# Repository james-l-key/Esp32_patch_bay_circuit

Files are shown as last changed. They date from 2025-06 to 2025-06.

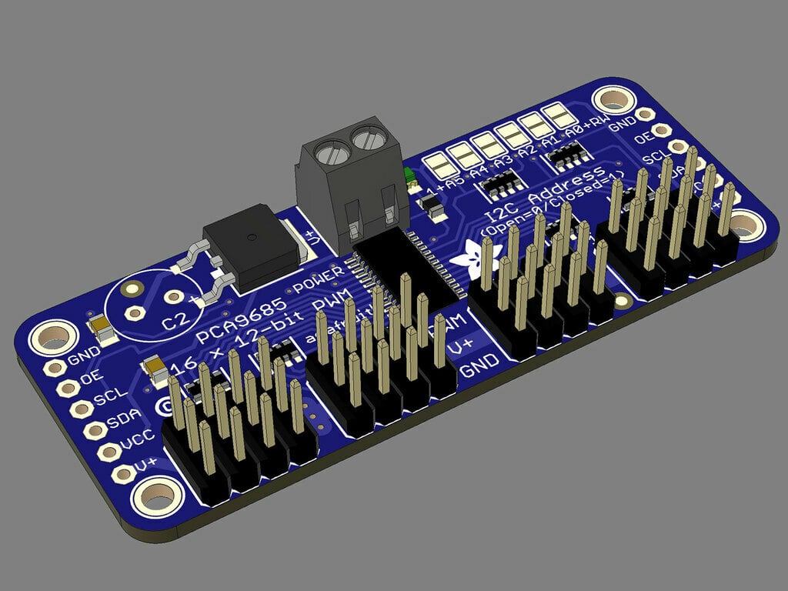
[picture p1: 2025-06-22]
DataSheets/adafruit_products_815_Servo_Driver_16_Channel.jpg

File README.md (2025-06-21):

# ESP32 Patch Bay - Hardware

This repository contains the hardware design files for the **ESP32 Patch Bay**, a project for dynamically reconfiguring guitar pedal signal chains. The main firmware repository can be found [here](https://github.com/phi/Esp32_patch_bay).

## Features
- **Schematic**: Designed in KiCad 9.0 (`circuit.kicad_sch`).
- **8-Pedal Support**: The design supports routing for up to 8 mono guitar pedals.
- **Audio Buffering**: Utilizes TL072 op-amps for input and output buffering to maintain signal integrity.
- **Power Isolation**: A TMA-1215D DC/DC converter generates isolated ±15V rails for the analog audio circuitry, ensuring low-noise operation.

## Hardware
The patch bay is built around the following key components:

- **Microcontroller**: ESP32-S3 (e.g., ESP32-S3-WROOM-1 module).
- **Audio Routing**:
  - CD4051B 8-channel analog multiplexers.
  - 3x TL072 dual op-amps for buffering.
- **Control**:
  - 74HC595 8-bit shift registers to control the multiplexers.
- **Power**:
  - The system is powered by a **12V DC** input.
  - Onboard regulators provide **±15V**, **+5V**, **-5V**, and **+3.3V** for all components.

For a complete list of components, please see the **Bill of Materials (BOM)** in the `docs` folder or the `HARDWARE.md` file.

## Power Requirements
- **Input Power**: The system uses an external **24V DC power supply**.
- **Isolated Dual Rails (±15V)**: Supplied by an LM7815 (+15V) and an inverting MC34063AP (-15V)
- **Regulated Rails**: Onboard linear regulators provide stable **+5V**, **-5V**, and **+3.3V** is supplied by the ESP32-s3-Devkit-C for the digital components and ESP32-S3.

## License
This project is licensed under the MIT License. See the [LICENSE](LICENSE) file for details.

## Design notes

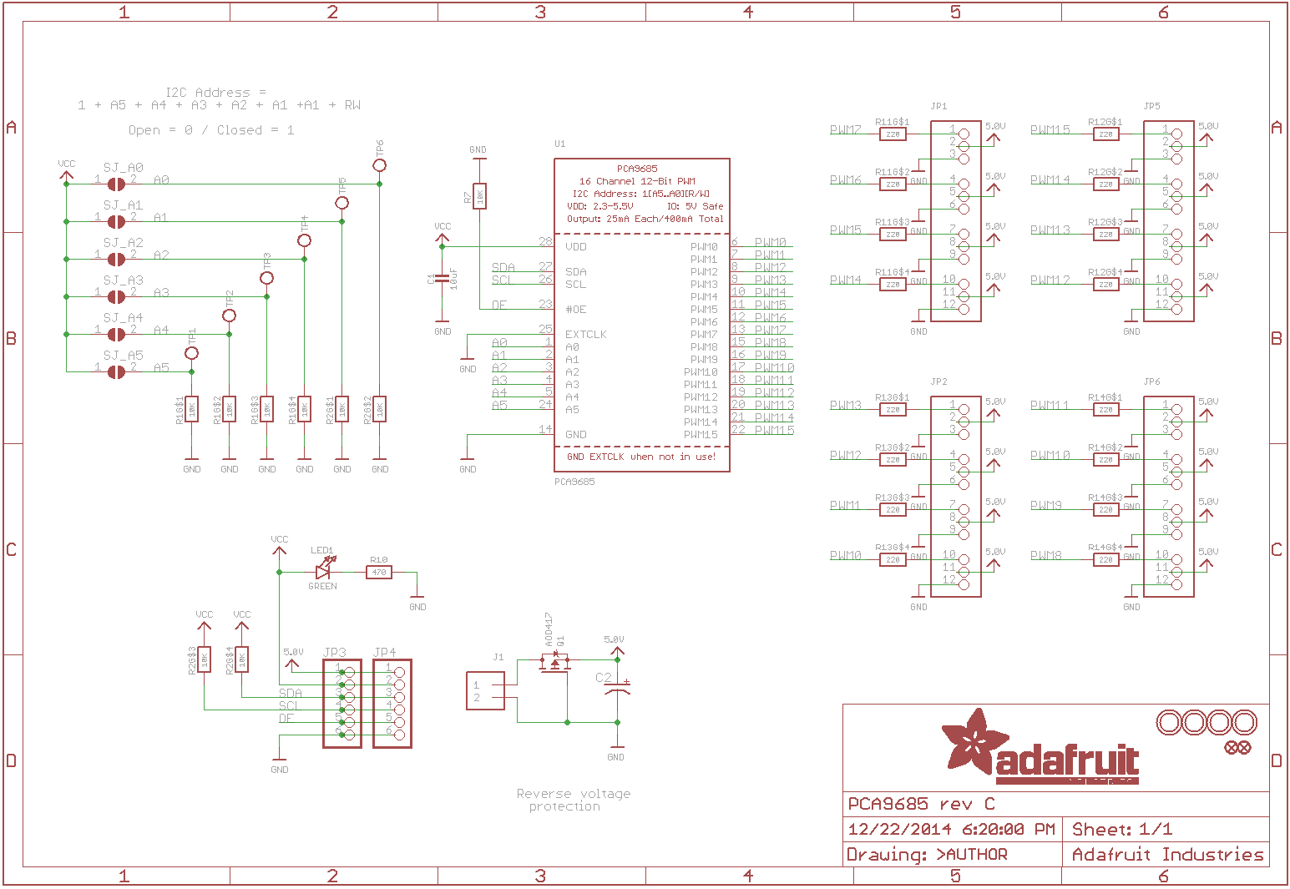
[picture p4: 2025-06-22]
DataSheets/adafruit_products_schem_PCA9685.png

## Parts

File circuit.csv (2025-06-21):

Id | Designator | Footprint | Quantity | Designation | Supplier and ref
1 | C703,C322,C601,C504,C108,C901,C325,C206,C502,C604,C507,C405,C319,C110,C335,C508,C404,C605,C323,C334,C333,C105,C606,C324,C336,C402,C201,C104,C331,C607,C103,C321,C106,C332,C329,C501,C505,C503,C326,C704,C701,C101,C602,C401,C702,C608,C107,C603,C327,C330,C506,C102,C403,C109,C320,C328 | C_Disc_D5.0mm_W2.5mm_P2.50mm | 56 | 0.1uF
2 | R315,R310,R905,R902,R301,R311,R316,R303,R307,R305,R903,R313,R908,R314,R901,R306,R317,R312,R308,R304,R309,R904,R302,R906,R907 | R_Axial_DIN0207_L6.3mm_D2.5mm_P7.62mm_Horizontal | 25 | 10k
3 | U503,U603,U402,U602,U504,U601,U604,U501,U502 | DIP-16_W7.62mm | 9 | CD4051B
4 | U401 | DIP-8_W7.62mm | 1 | ADG419BN
5 | C304,C316,C301,C305,C307,C205,C312,C318,C202,C308,C309,C313,C310,C302,C306,C315,C303,C311,C337,C317,C314 | C_Disc_D5.0mm_W2.5mm_P2.50mm | 21 | 1uF
6 | L302,L303,L304,L501,L602,L601,L502,L301 | WE-UKW_74275010 | 8 | 600R@100Mhz
7 | U704,U901,U701,U702,U703 | DIP-16_W7.62mm | 5 | 74HC595
8 | SW110 | PinHeader_1x02_P2.54mm_Vertical | 1 | Preset
9 | L201 | L_Radial_D10.0mm_P5.00mm_Fastron_07M | 1 | 150uH
10 | C208 | CP_Radial_D5.0mm_P2.50mm | 1 | 220uF 16v
11 | SW109 | PinHeader_1x02_P2.54mm_Vertical | 1 | Pedal_5
12 | J316 | Jack | 1 | FX_S_8
13 | Disp101 | PinHeader_1x04_P2.54mm_Vertical | 1 | ~
14 | J305 | Jack | 1 | FX_R_5
15 | U303,U305,U304,U307,U301,U308,U309,U302,U306 | DIP-8_W7.62mm | 9 | TL072
16 | R201 | R_Axial_DIN0207_L6.3mm_D2.5mm_P7.62mm_Horizontal | 1 | 1.5
17 | C209,C204,C211 | CP_Radial_D5.0mm_P2.50mm | 3 | 100uF 50v
18 | J311 | Jack | 1 | FX_S_3
19 | U205 | TO-220-5_Vertical | 1 | LM2576HVT-5
20 | R101 | R_Axial_DIN0207_L6.3mm_D2.5mm_P7.62mm_Horizontal | 1 | 100
21 | J201 | BarrelJack_CUI_PJ-063AH_Horizontal_CircularHoles | 1 | Barrel_Jack
22 | J315 | Jack | 1 | FX_S_7
23 | U201 | DIP-8_W7.62mm | 1 | MC34063AP
24 | L202 | L_Radial_D10.0mm_P5.00mm_Fastron_07M | 1 | 220uH
25 | SW106 | PinHeader_1x02_P2.54mm_Vertical | 1 | Pedal_8
26 | R202 | R_Axial_DIN0207_L6.3mm_D2.5mm_P7.62mm_Horizontal | 1 | 1k
27 | SW104 | PinHeader_1x02_P2.54mm_Vertical | 1 | Pedal_7
28 | J302 | Jack | 1 | FX_R_2
29 | J314 | Jack | 1 | FX_S_6
30 | U101 | ESP32-S3-DevKitC | 1 | ESP32-S3-DevKitC
31 | SW107 | PinHeader_1x02_P2.54mm_Vertical | 1 | Pedal_4
32 | J312 | Jack | 1 | FX_S_4
33 | SW102 | PinHeader_1x02_P2.54mm_Vertical | 1 | Pedal_6
34 | D201,D202 | D_DO-41_SOD81_P10.16mm_Horizontal | 2 | 1N5822
35 | J317 | Jack | 1 | Guitar_In
36 | RV101 | Potentiometer_Bourns_3339P_Vertical | 1 | 500
37 | J310 | Jack | 1 | FX_S_2
38 | J801 | PinHeader_1x06_P2.54mm_Vertical | 1 | Conn_01x06_Pin
39 | J304 | Jack | 1 | FX_R_4
40 | D203 | D_DO-41_SOD81_P10.16mm_Horizontal | 1 | 1N5819
41 | D101 | PinHeader_1x02_P2.54mm_Vertical | 1 | LED_PWR
42 | SW101 | PinHeader_1x02_P2.54mm_Vertical | 1 | Pedal_1
43 | J313 | Jack | 1 | FX_S_5
44 | F201 | Fuse_Bourns_MF-RG500 | 1 | Polyfuse_Small
45 | U203 | TO-220-3_Vertical | 1 | LM7905_TO220
46 | C210 | C_Disc_D5.0mm_W2.5mm_P2.50mm | 1 | 470pF
47 | J318 | Jack | 1 | Amp_Out
48 | SW103 | PinHeader_1x02_P2.54mm_Vertical | 1 | Pedal_2
49 | J308 | Jack | 1 | FX_R_8
50 | SW105 | PinHeader_1x02_P2.54mm_Vertical | 1 | Pedal_3
51 | U202 | TO-220-3_Vertical | 1 | LM7815_TO220
52 | J309 | Jack | 1 | FX_S_1
53 | J306 | Jack | 1 | FX_R_6
54 | J307 | Jack | 1 | FX_R_7
55 | J301 | Jack | 1 | FX_R_1
56 | R203 | R_Axial_DIN0207_L6.3mm_D2.5mm_P7.62mm_Horizontal | 1 | 11k
57 | SW108 | PinHeader_1x02_P2.54mm_Vertical | 1 | Program
58 | J303 | Jack | 1 | FX_R_3

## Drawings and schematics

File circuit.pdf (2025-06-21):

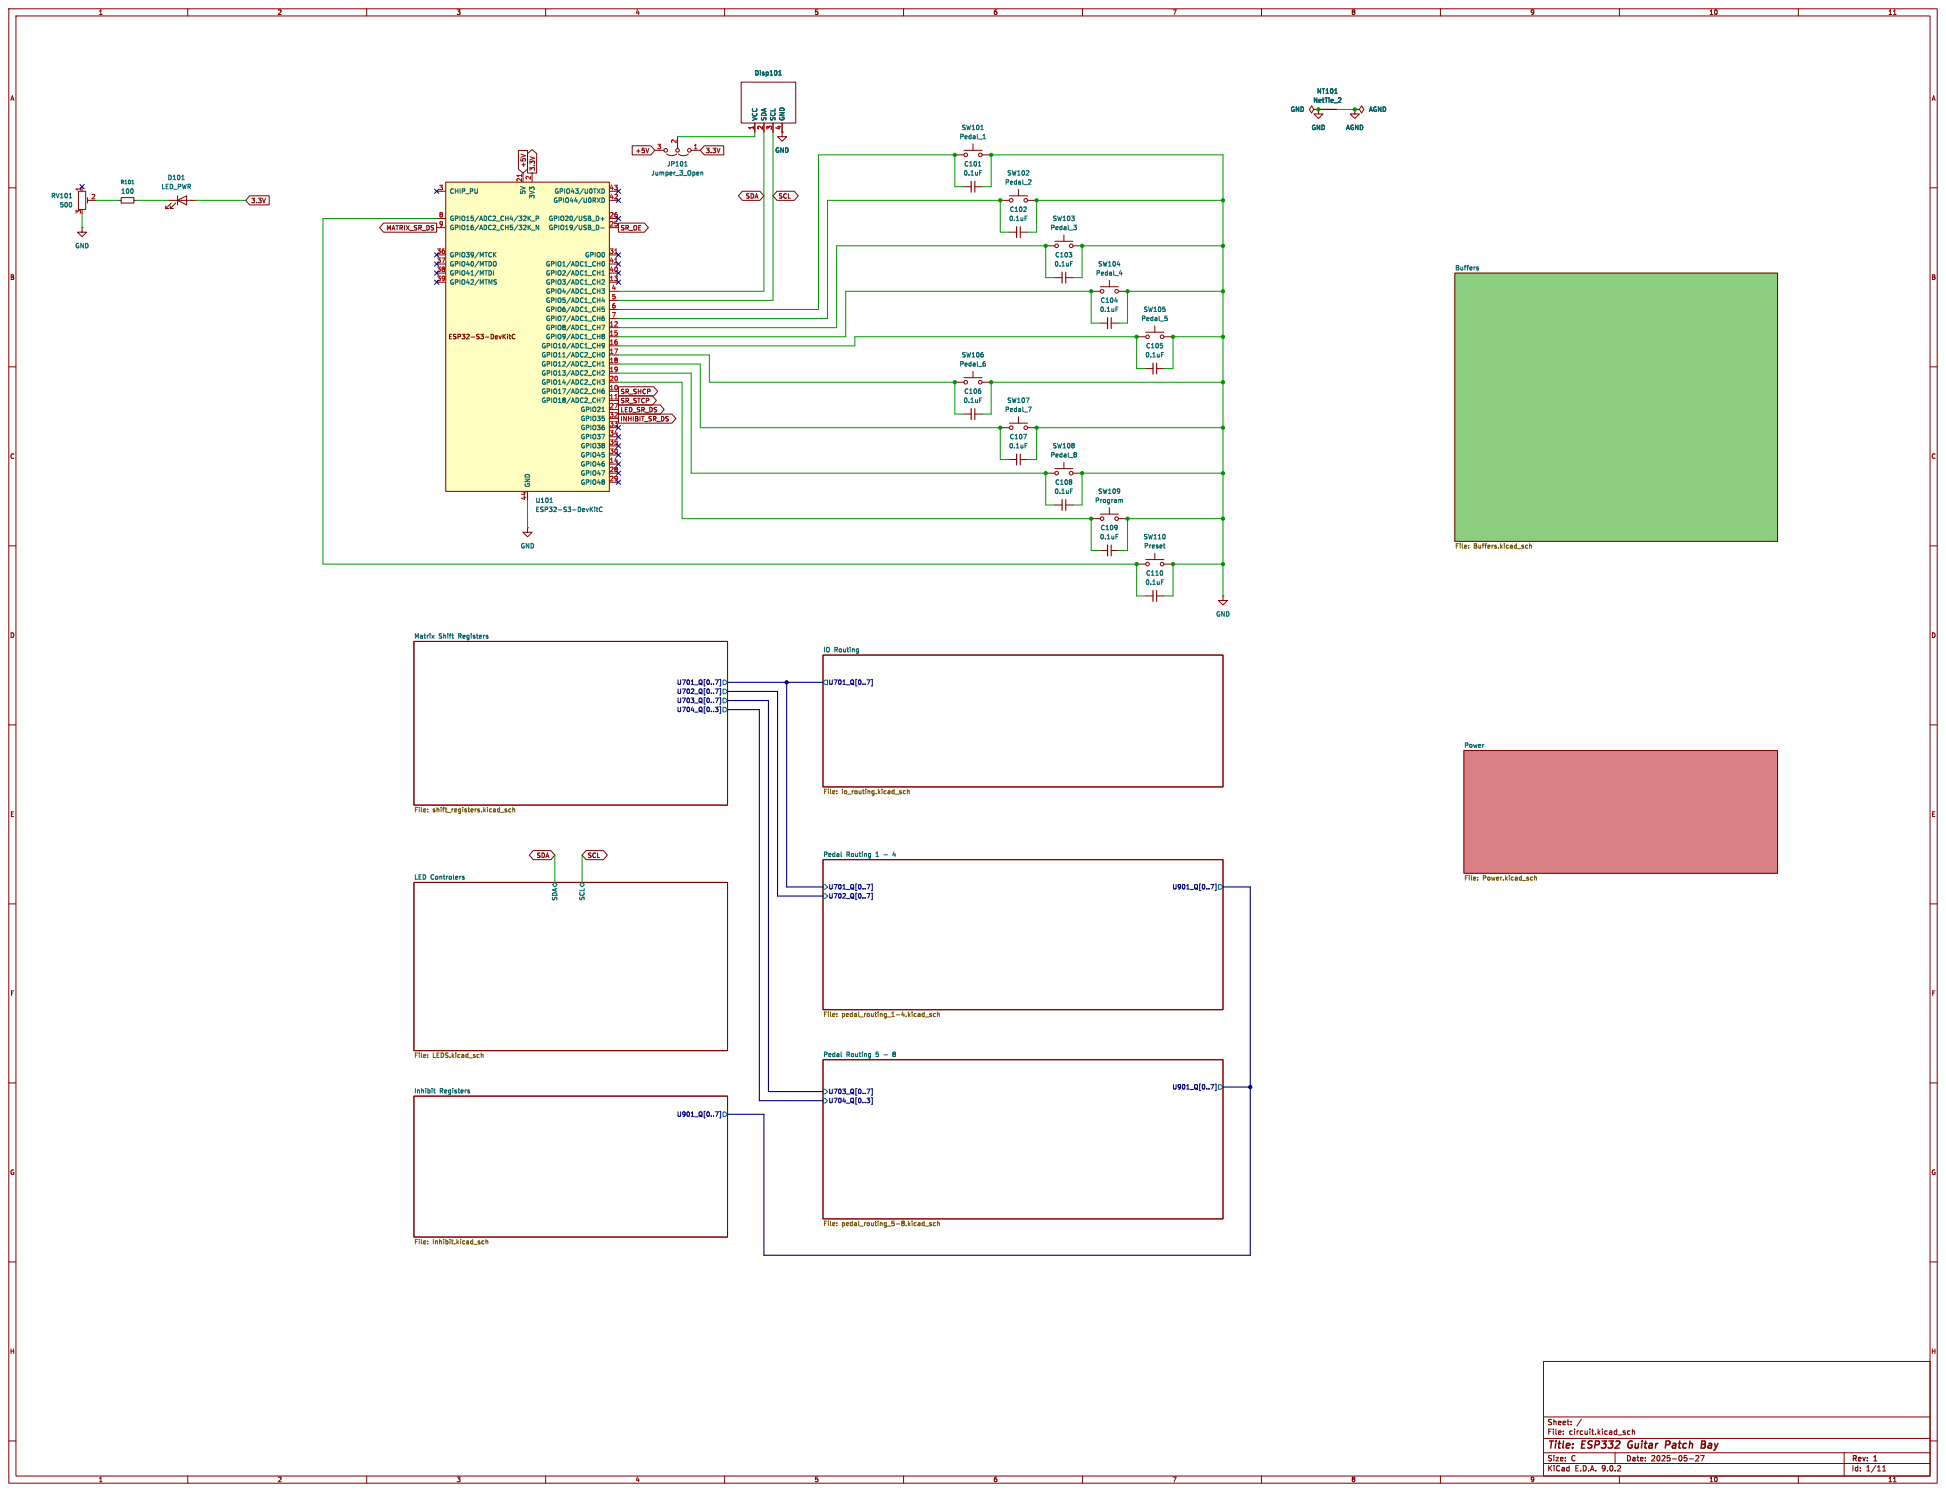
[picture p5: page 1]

2 CHIP_PU 3 GPIO15/ADC2_CH4/32K_P 8 GPIO16/ADC2_CH5/32K_N 9 GPIO39/MTCK 36 GPIO40/MTDO 37 GPIO41/MTDI 38 5V 21 GPIO20/USB_D+ 26 GPIO19/USB_D- 25 GPIO0 31 GPIO3/ADC1_CH2 13 GPIO4/ADC1_CH3 4 GPIO5/ADC1_CH4 5 GPIO6/ADC1_CH5 6 GPIO7/ADC1_CH6 7 GPIO8/ADC1_CH7 12 GPIO9/ADC1_CH8 15 GPIO10/ADC1_CH9 16 GPIO11/ADC2_CH0 17 GPIO12/ADC2_CH1 18 GPIO14/ADC2_CH3 20 GPIO17/ADC2_CH6 10 GPIO18/ADC2_CH7 11 GPIO21 27 GPIO35 32 GPIO36 33 GPIO37 34 GPIO38 35 GPIO45 30 GPIO47 28 GPIO48 29 U101 ESP32-S3-DevKitC

Buffers File: Buffers.kicad_sch Power File: Power.kicad_sch U901_Q[0..7]

U704_Q[0..3] Matrix Shift Registers File: shift_registers.kicad_sch

LED Controlers File: LEDS.kicad_sch

Inhibit Registers File: Inhibit.kicad_sch

File: circuit.kicad_sch Sheet: /
Id: 1/11 Title: ESP332 Guitar Patch Bay

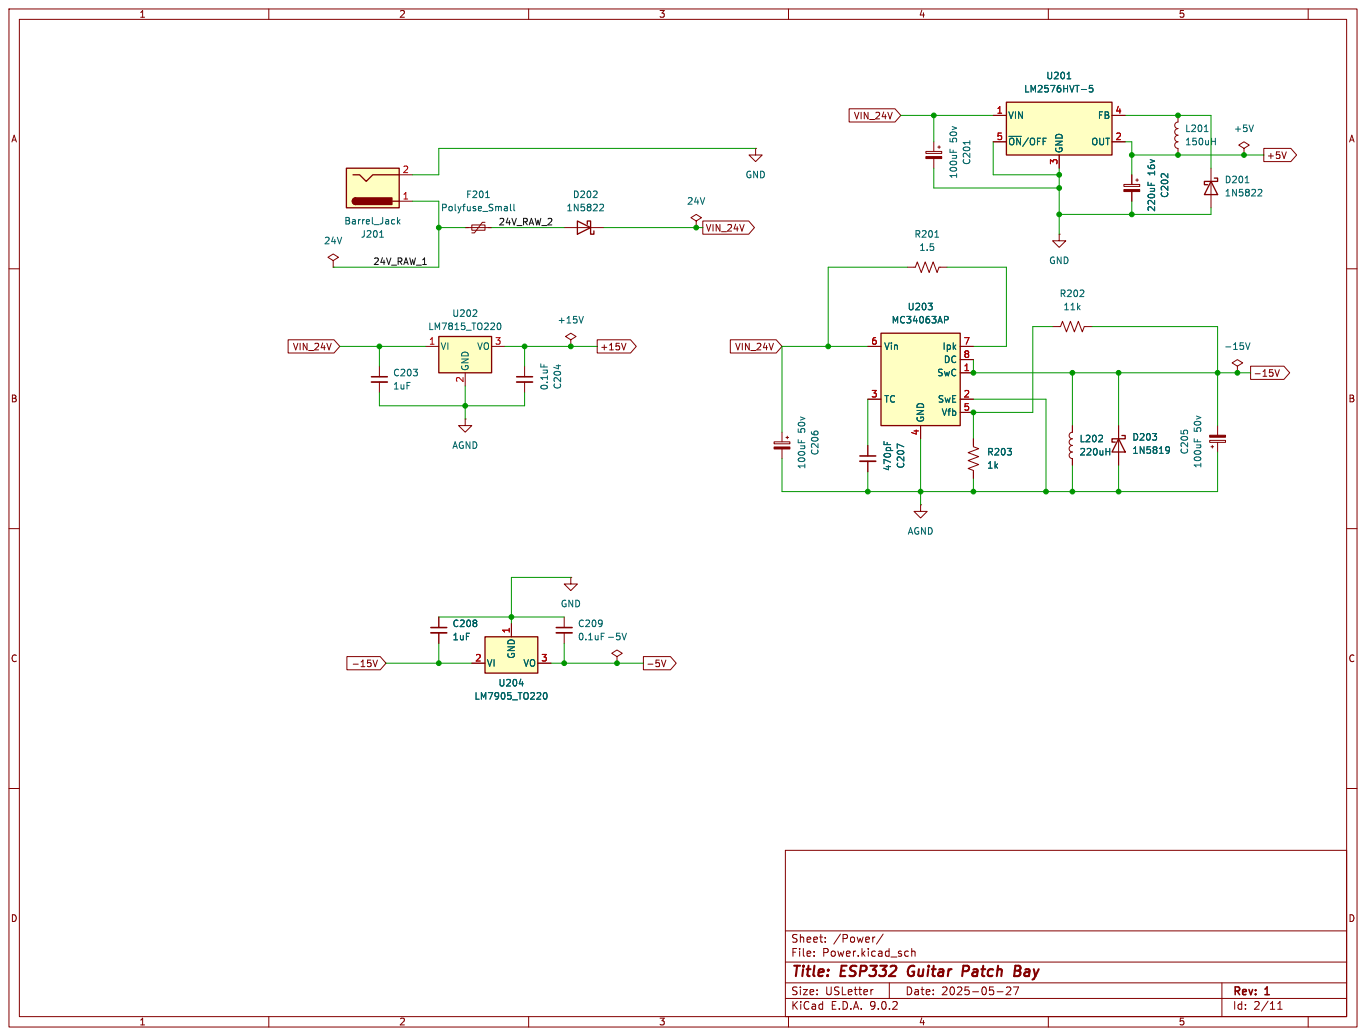
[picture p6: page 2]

Id: 2/11 Title: ESP332 Guitar Patch Bay

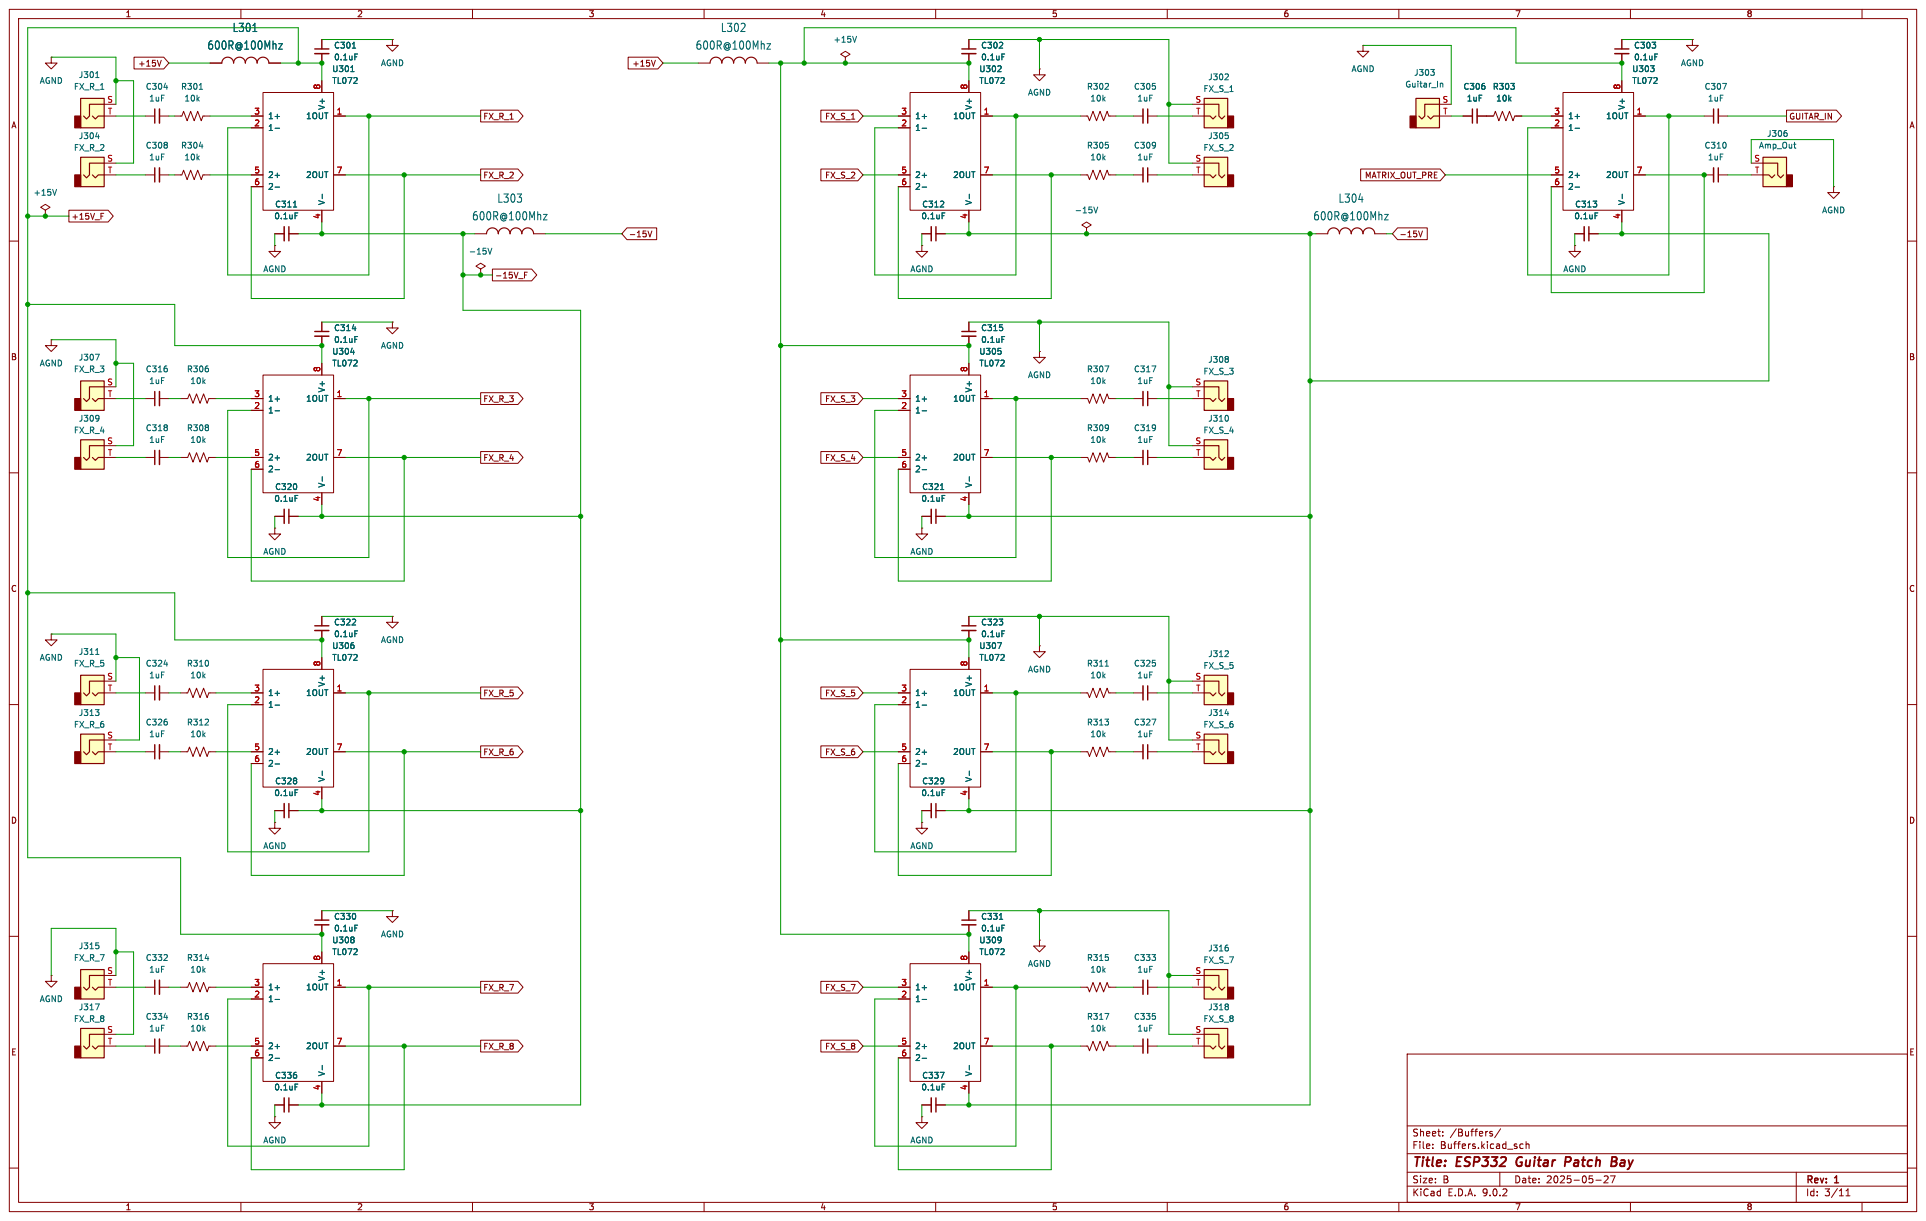
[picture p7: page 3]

File: Buffers.kicad_sch Sheet: /Buffers/
Id: 3/11 Title: ESP332 Guitar Patch Bay

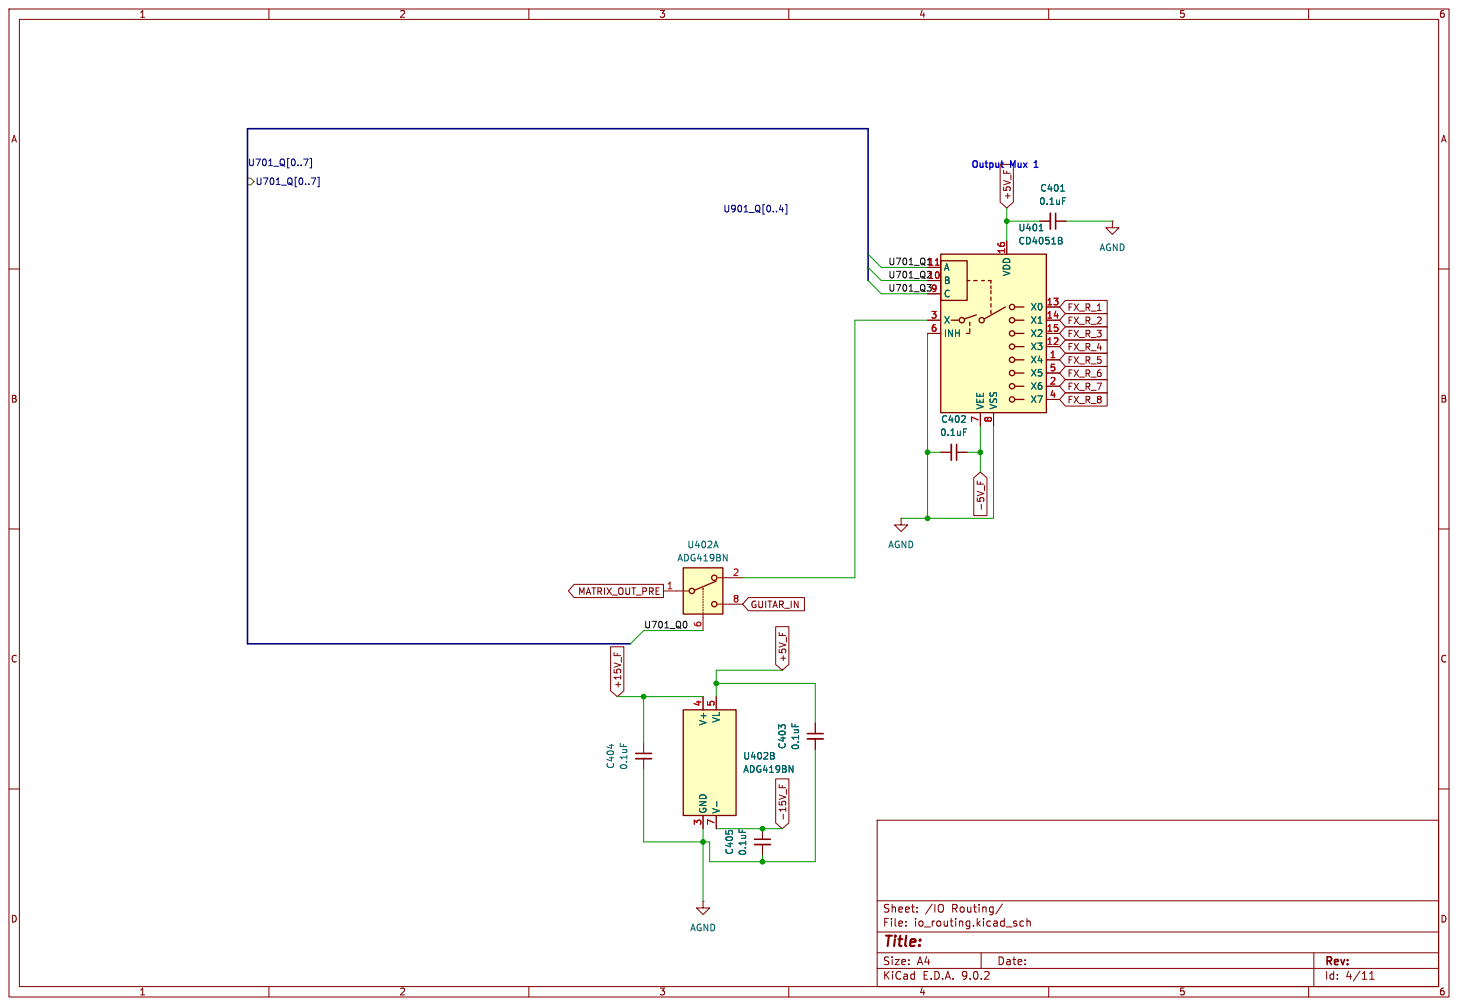
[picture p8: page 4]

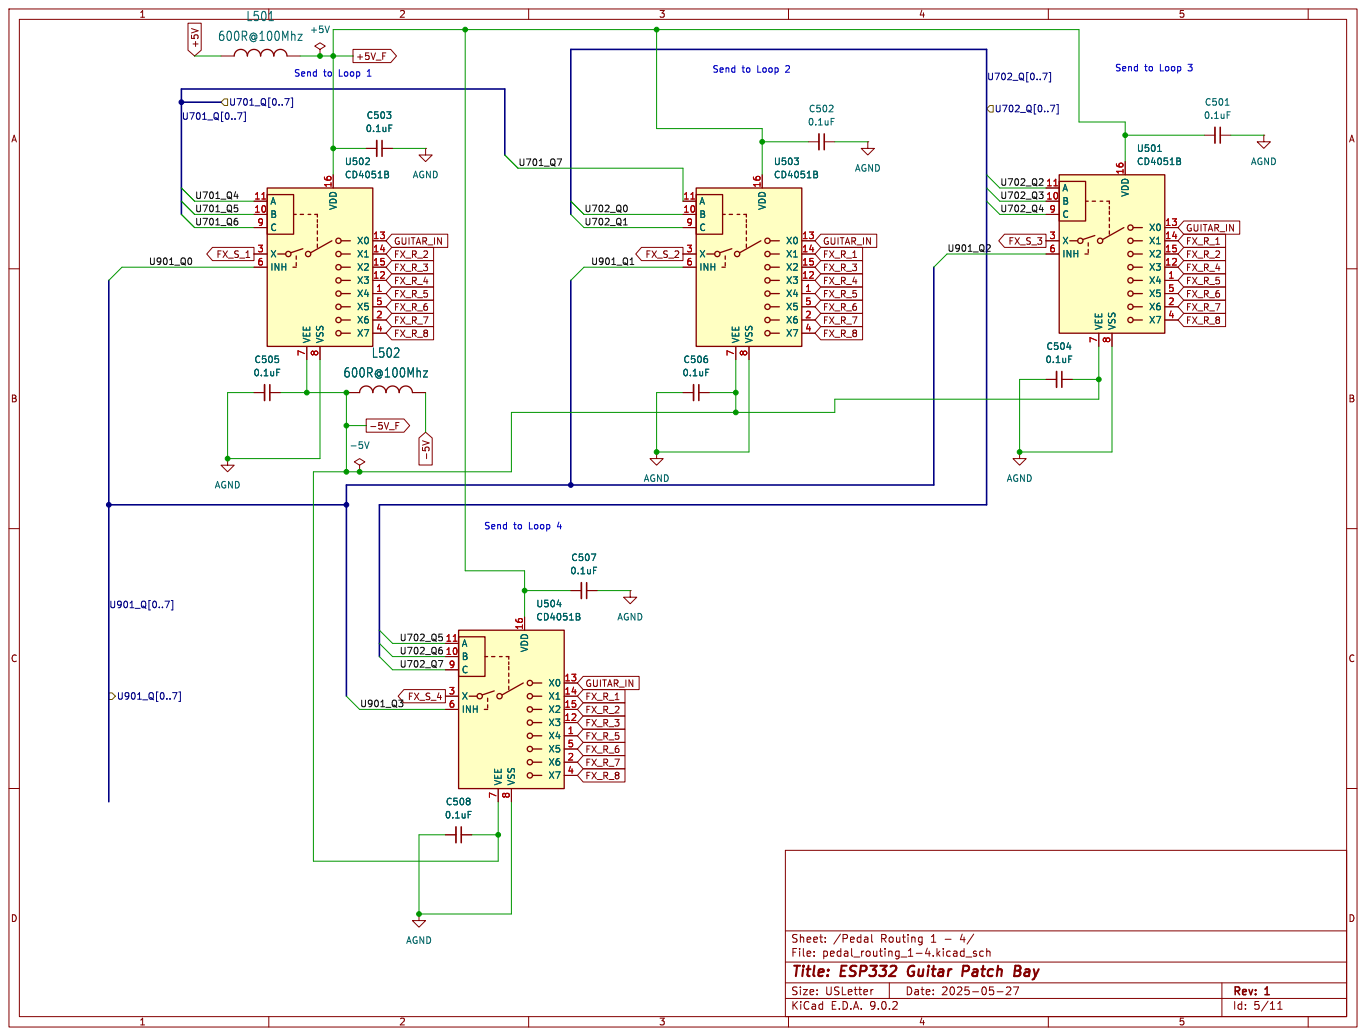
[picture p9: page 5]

Id: 5/11 Title: ESP332 Guitar Patch Bay

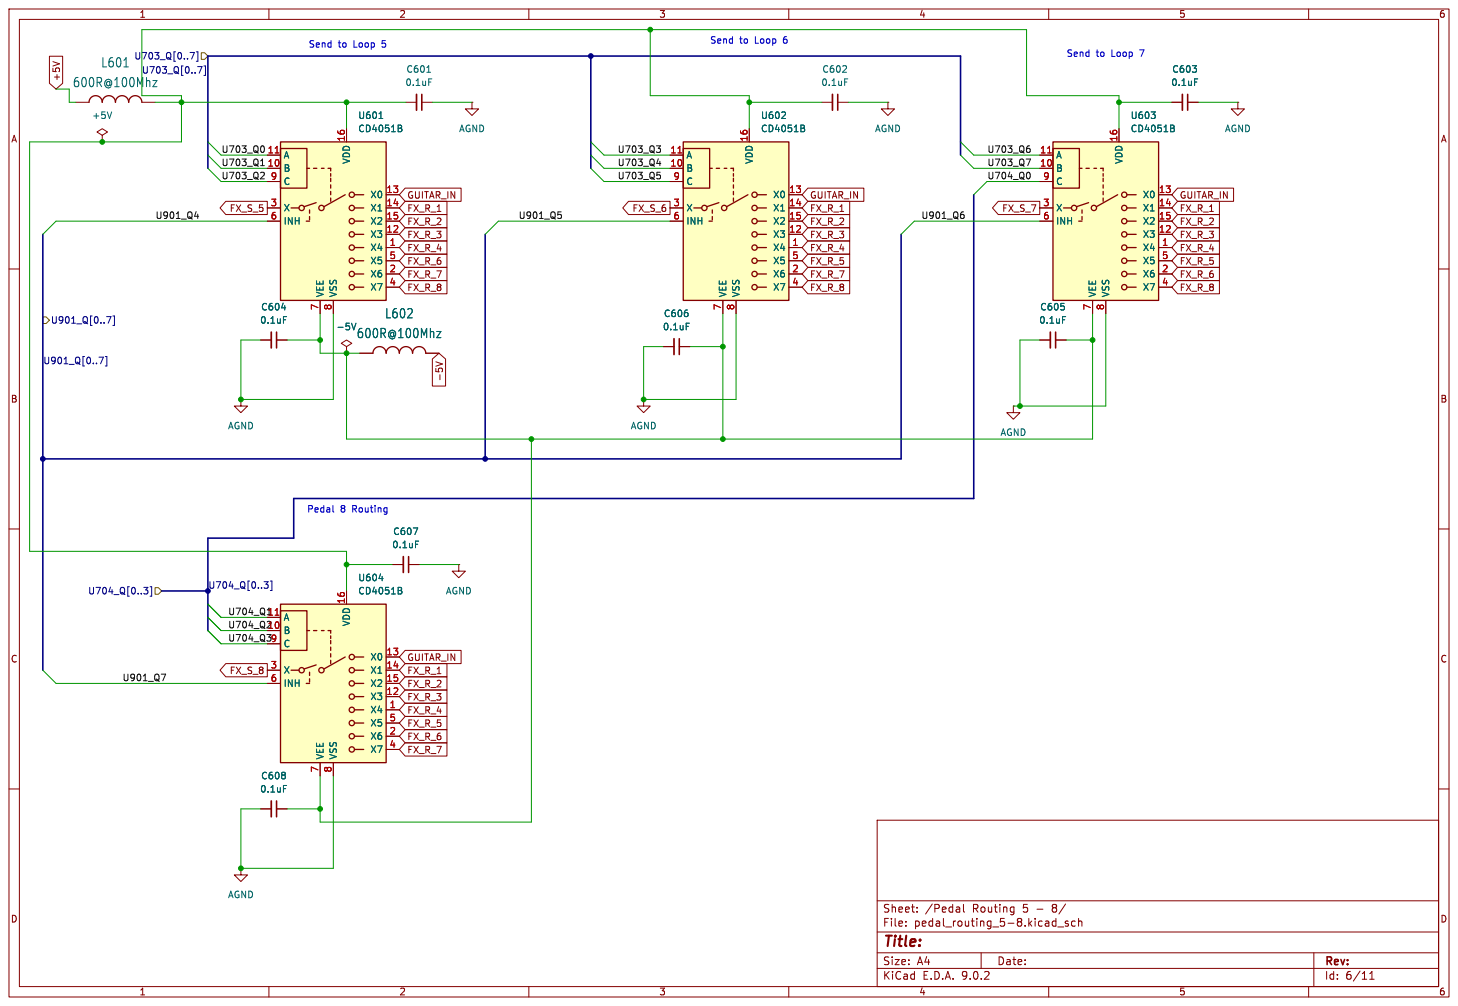
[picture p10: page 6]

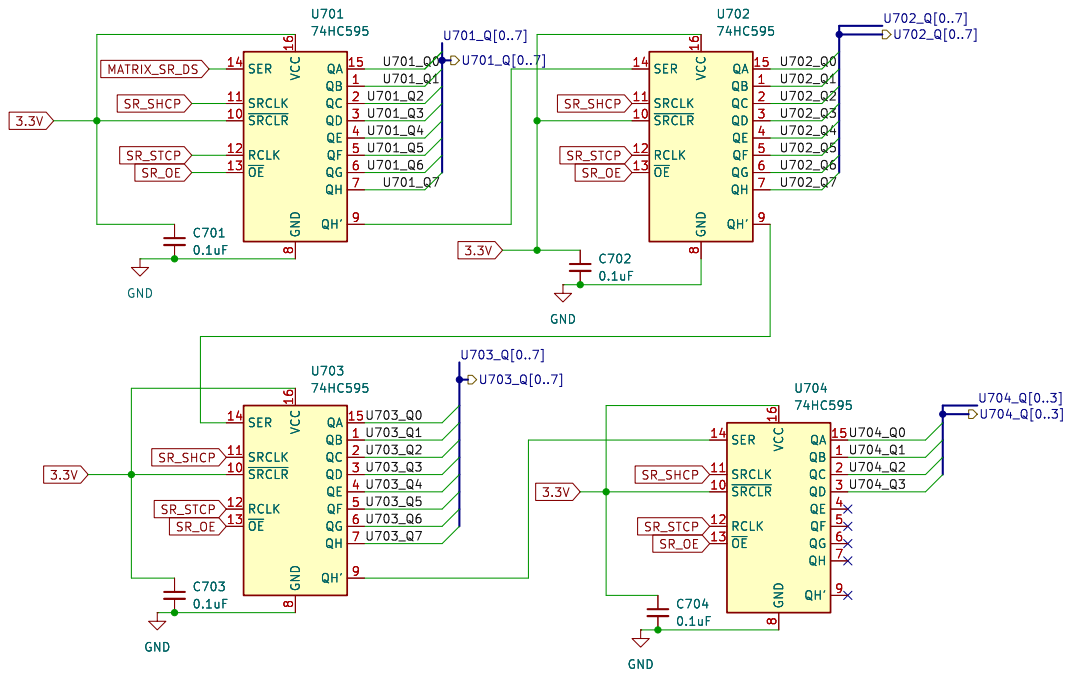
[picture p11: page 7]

8 QA 15 QB 1 QC 2 QD 3 QE 4 QF 5 QG 6 QH 7 QH' 9 GND
SR_SHCP

Id: 7/11 Title: ESP332 Guitar Patch Bay

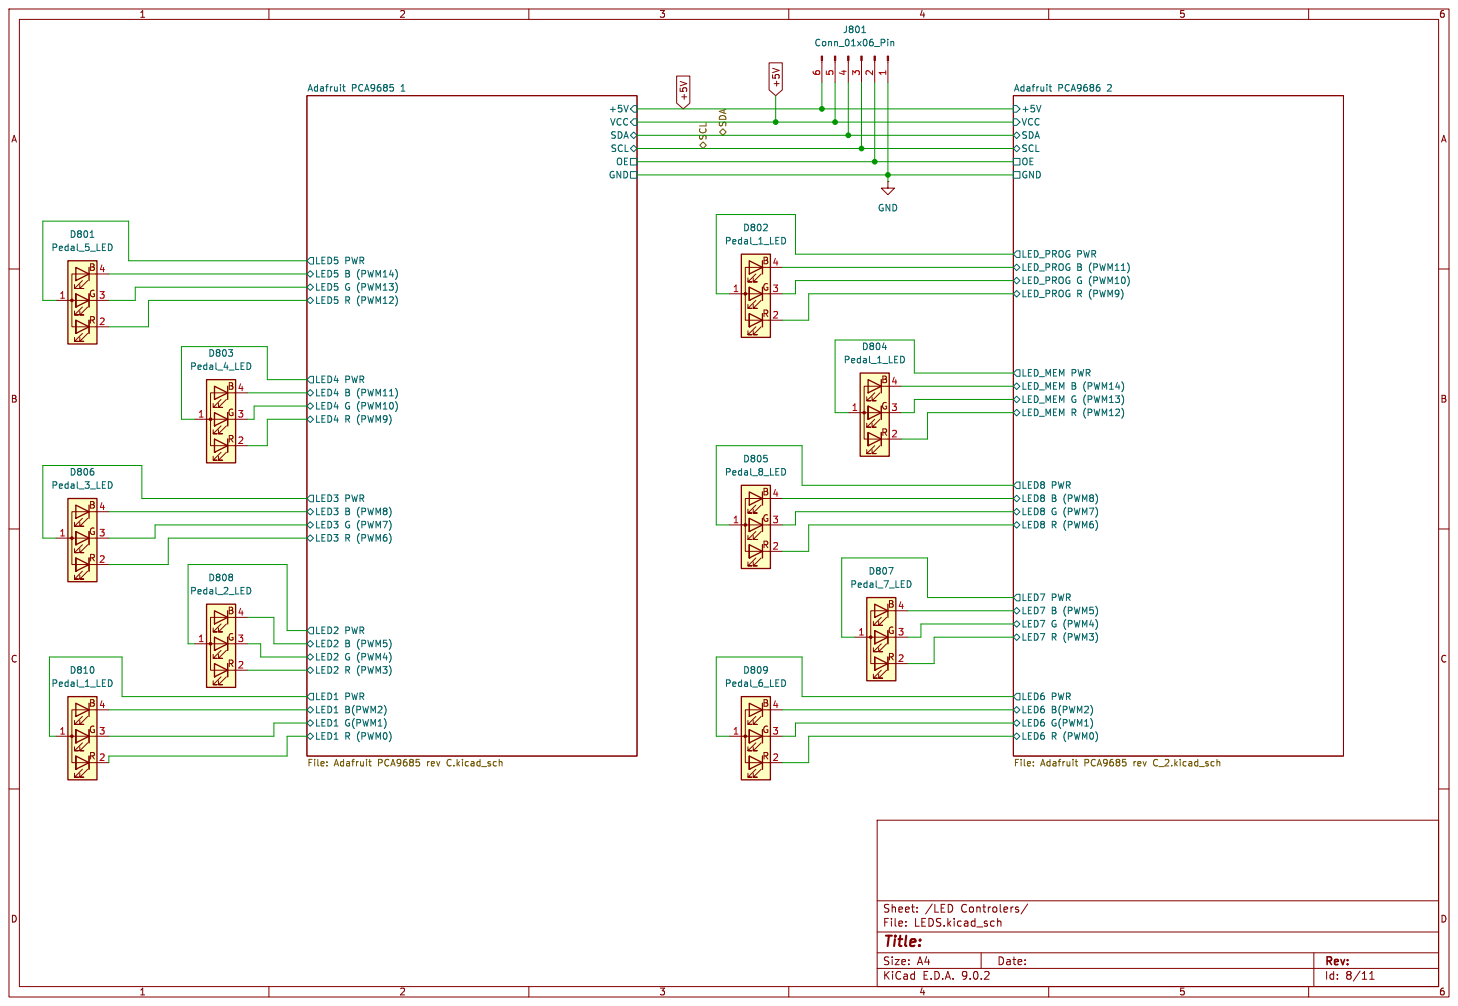
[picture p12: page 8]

Id: 8/11 Title: File: LEDS.kicad_sch Sheet: /LED Controlers/

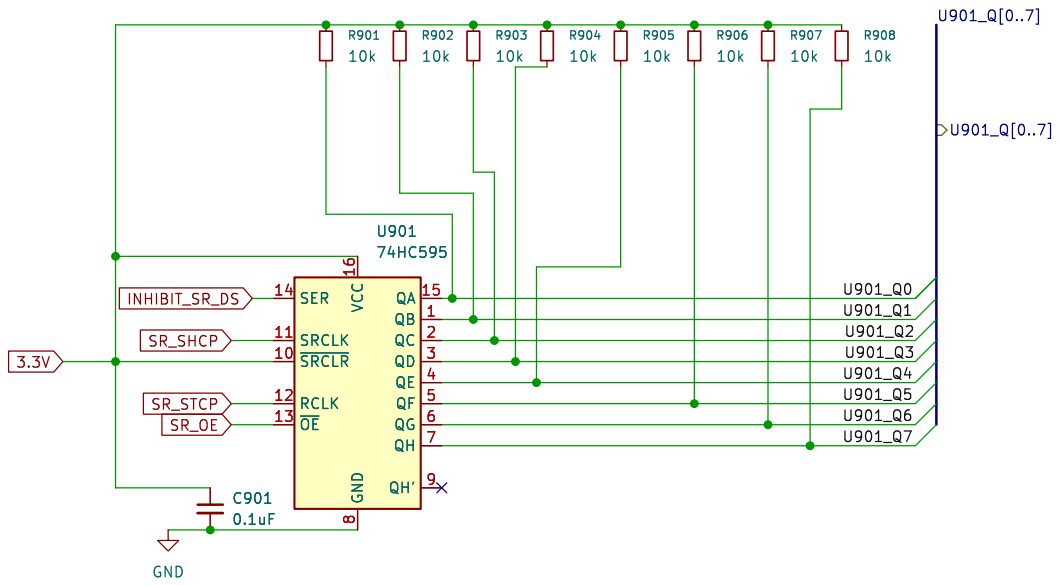
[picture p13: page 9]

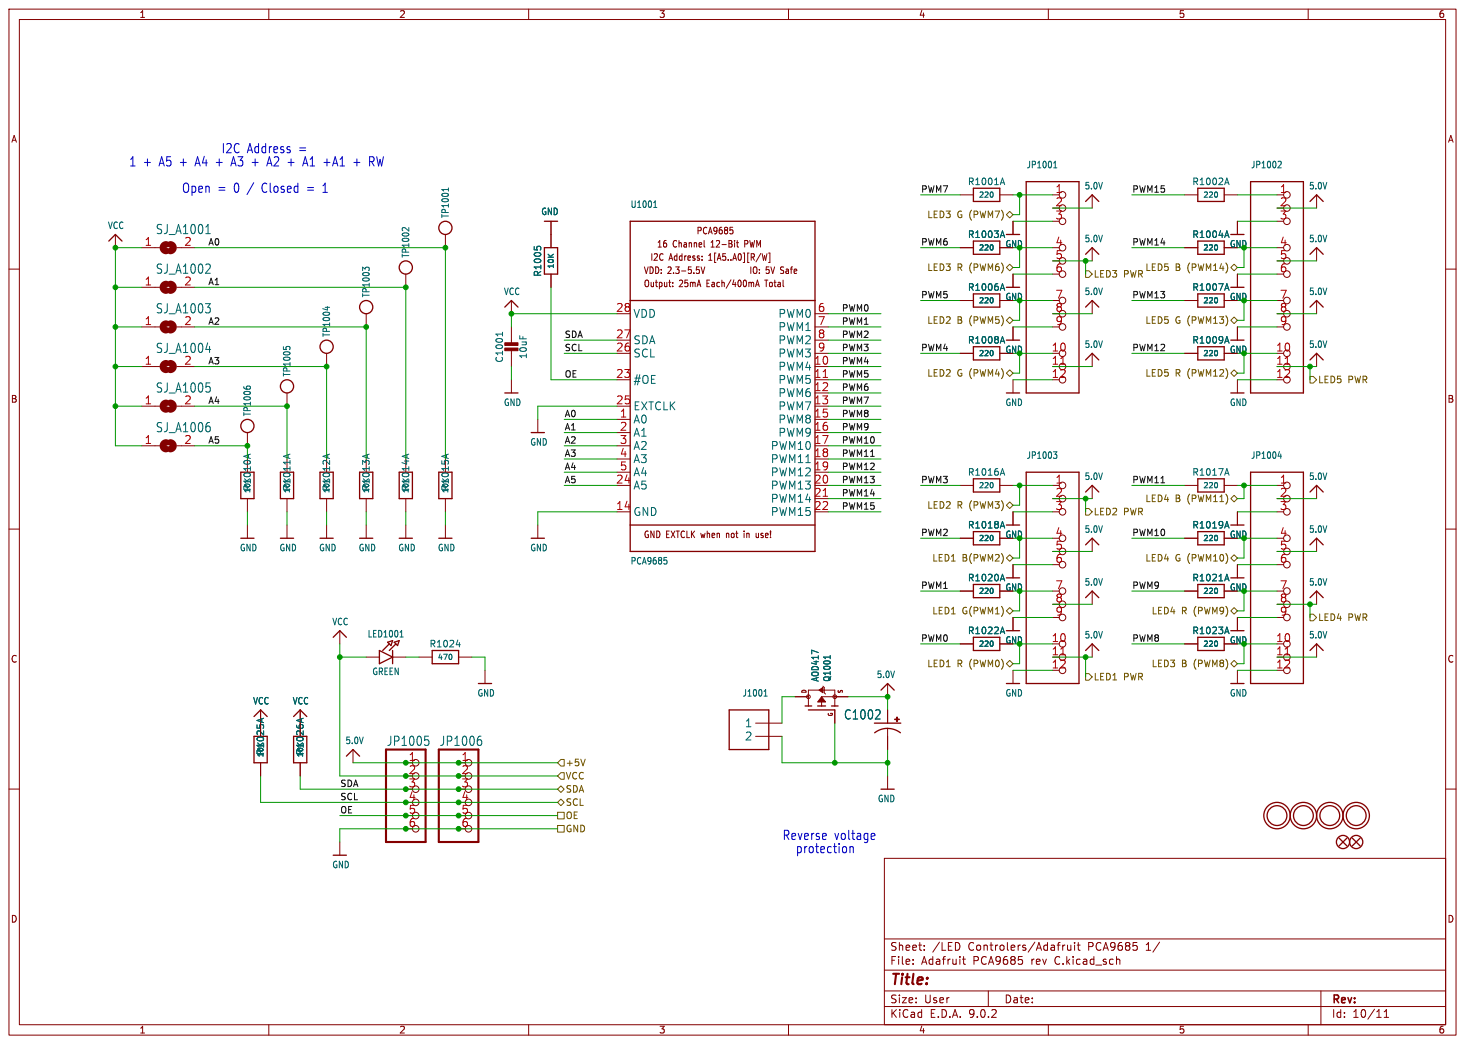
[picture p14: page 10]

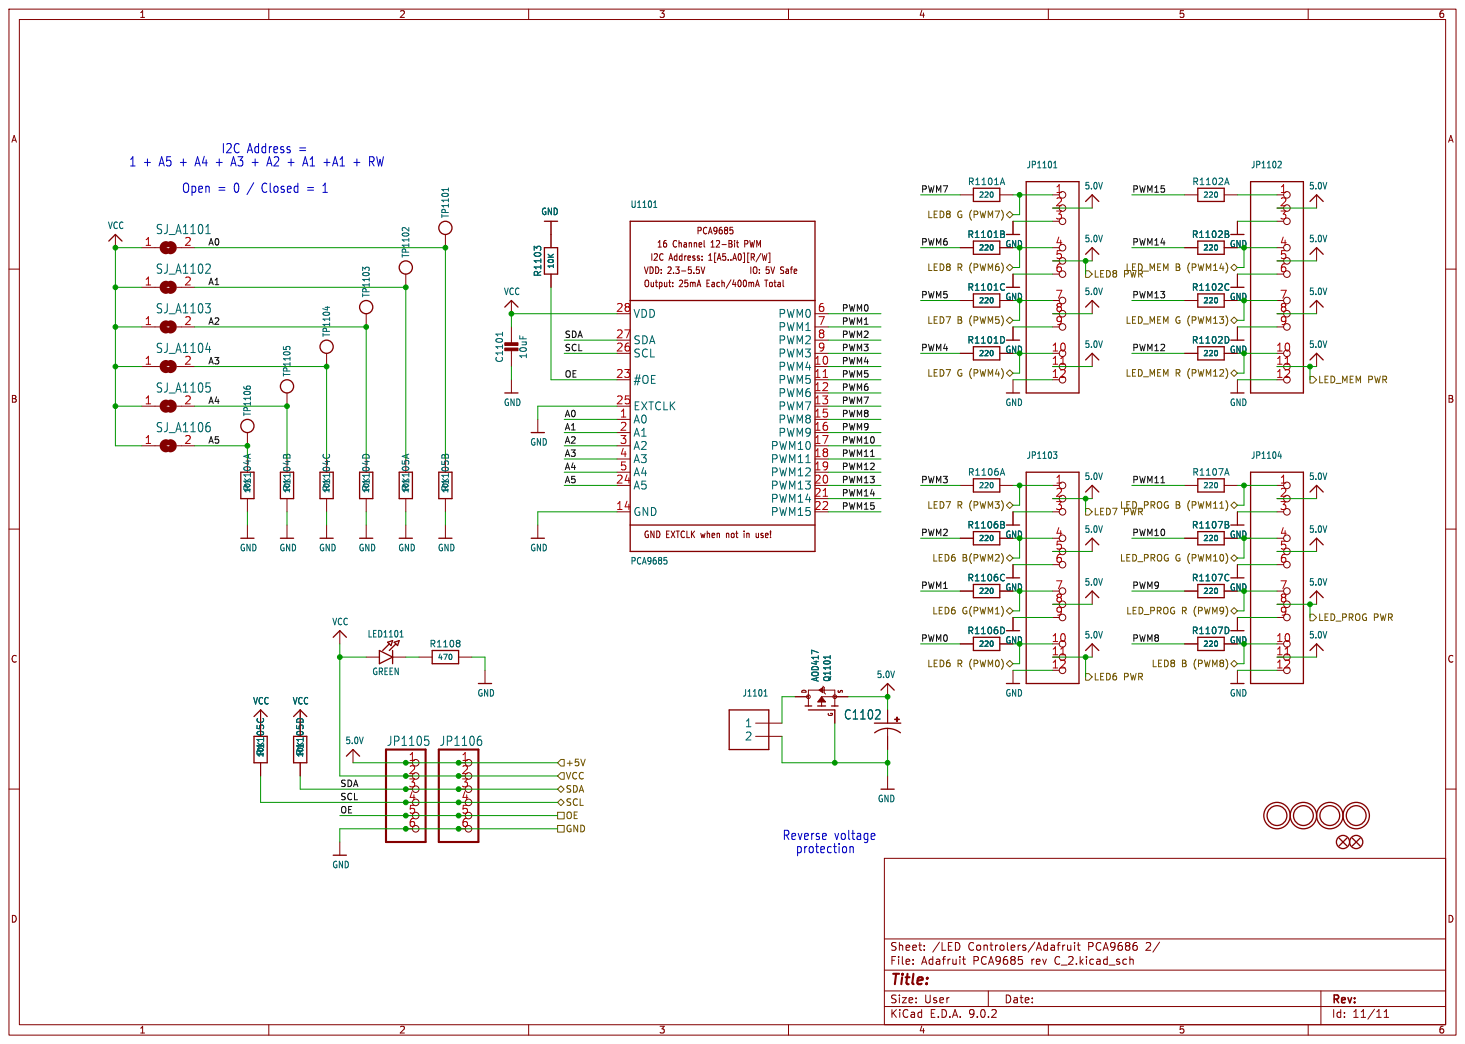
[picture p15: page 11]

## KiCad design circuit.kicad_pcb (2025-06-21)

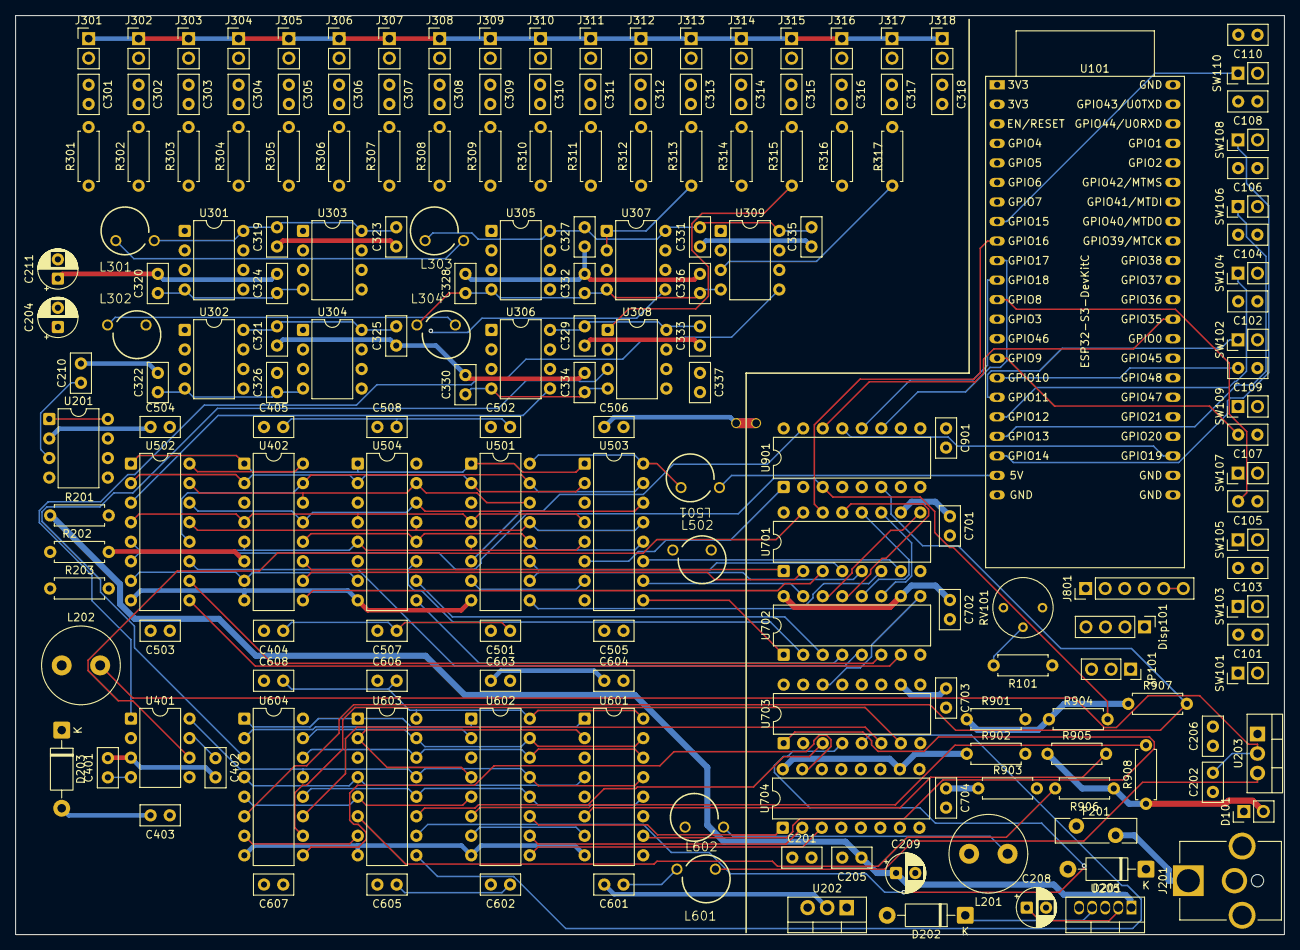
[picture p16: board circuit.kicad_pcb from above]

Board: 4 copper layers, 165.0 x 119.5 mm, 189 parts (0 on the bottom side), 155 nets.

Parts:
C101, C102, C103, C104, C105, C106, C107, C108, C109, C110, C201, C206, C319, C320, C321, C322, C323, C324, C325, C326, C327, C328, C329, C330, C331, C332, C333, C334, C335, C336, C401, C402, C403, C404, C405, C501, C502, C503, C504, C505, C506, C507, C508, C601, C602, C603, C604, C605, C606, C607, C608, C701, C702, C703, C704, C901: 0.1uF; C_Disc_D5.0mm_W2.5mm_P2.50mm
C202, C205, C301, C302, C303, C304, C305, C306, C307, C308, C309, C310, C311, C312, C313, C314, C315, C316, C317, C318, C337: 1uF; C_Disc_D5.0mm_W2.5mm_P2.50mm
C204, C209, C211: 100uF 50v; CP_Radial_D5.0mm_P2.50mm
C208: 220uF 16v; CP_Radial_D5.0mm_P2.50mm
C210: 470pF; C_Disc_D5.0mm_W2.5mm_P2.50mm
D101: LED_PWR; PinHeader_1x02_P2.54mm_Vertical
D201, D202: 1N5822; D_DO-41_SOD81_P10.16mm_Horizontal
D203: 1N5819; D_DO-41_SOD81_P10.16mm_Horizontal
Disp101: PinHeader_1x04_P2.54mm_Vertical
F201: Polyfuse_Small; Fuse_Bourns_MF-RG500
J201: Barrel_Jack; BarrelJack_CUI_PJ-063AH_Horizontal_CircularHoles
J301: FX_R_1; Jack
J302: FX_R_2; Jack
J303: FX_R_3; Jack
J304: FX_R_4; Jack
J305: FX_R_5; Jack
J306: FX_R_6; Jack
J307: FX_R_7; Jack
J308: FX_R_8; Jack
J309: FX_S_1; Jack
J310: FX_S_2; Jack
J311: FX_S_3; Jack
J312: FX_S_4; Jack
J313: FX_S_5; Jack
J314: FX_S_6; Jack
J315: FX_S_7; Jack
J316: FX_S_8; Jack
J317: Guitar_In; Jack
J318: Amp_Out; Jack
J801: Conn_01x06_Pin; PinHeader_1x06_P2.54mm_Vertical
JP101: Jumper_3_Open; PinSocket_1x03_P2.54mm_Vertical
L201: 150uH; L_Radial_D10.0mm_P5.00mm_Fastron_07M
L202: 220uH; L_Radial_D10.0mm_P5.00mm_Fastron_07M
L301, L302, L303, L304, L501, L502, L601, L602: 600R@100Mhz; WE-UKW_74275010
NT101: NetTie_2; NetTie-2_THT_Pad1.0mm
R101: 100; R_Axial_DIN0207_L6.3mm_D2.5mm_P7.62mm_Horizontal
R201: 1.5; R_Axial_DIN0207_L6.3mm_D2.5mm_P7.62mm_Horizontal
R202: 1k; R_Axial_DIN0207_L6.3mm_D2.5mm_P7.62mm_Horizontal
R203: 11k; R_Axial_DIN0207_L6.3mm_D2.5mm_P7.62mm_Horizontal
R301, R302, R303, R304, R305, R306, R307, R308, R309, R310, R311, R312, R313, R314, R315, R316, R317, R901, R902, R903, R904, R905, R906, R907, R908: 10k; R_Axial_DIN0207_L6.3mm_D2.5mm_P7.62mm_Horizontal
RV101: 500; Potentiometer_Bourns_3339P_Vertical
SW101: Pedal_1; PinHeader_1x02_P2.54mm_Vertical
SW102: Pedal_6; PinHeader_1x02_P2.54mm_Vertical
SW103: Pedal_2; PinHeader_1x02_P2.54mm_Vertical
SW104: Pedal_7; PinHeader_1x02_P2.54mm_Vertical
SW105: Pedal_3; PinHeader_1x02_P2.54mm_Vertical
SW106: Pedal_8; PinHeader_1x02_P2.54mm_Vertical
SW107: Pedal_4; PinHeader_1x02_P2.54mm_Vertical
SW108: Program; PinHeader_1x02_P2.54mm_Vertical
SW109: Pedal_5; PinHeader_1x02_P2.54mm_Vertical
SW110: Preset; PinHeader_1x02_P2.54mm_Vertical
U101: ESP32-S3-DevKitC
U201: MC34063AP; DIP-8_W7.62mm
U202: LM7815_TO220; TO-220-3_Vertical
U203: LM7905_TO220; TO-220-3_Vertical
U205: LM2576HVT-5; TO-220-5_Vertical
U301, U302, U303, U304, U305, U306, U307, U308, U309: TL072; DIP-8_W7.62mm
U401: ADG419BN; DIP-8_W7.62mm
U402, U501, U502, U503, U504, U601, U602, U603, U604: CD4051B; DIP-16_W7.62mm
U701, U702, U703, U704, U901: 74HC595; DIP-16_W7.62mm

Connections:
3.3V: C701.1, C702.1, C703.1, C704.1, C901.1, D101.2 (A), JP101.1 (A), R901.1, R902.1, R903.1, R904.1, R905.1, R906.1, R907.1, R908.1, U101.1 (3V3), U101.2 (3V3), U701.10 (~SRCLR), U701.16 (VCC), U702.10 (~SRCLR), U702.16 (VCC), U703.10 (~SRCLR), U703.16 (VCC), U704.10 (~SRCLR), U704.16 (VCC), U901.10 (~SRCLR), U901.16 (VCC)
5.0V: J801.5, J801.6
+5V: C208.1, JP101.3 (B), L201.1, L501.1, L601.1, U101.21 (5V), U205.2 (OUT)
+5V_F: C403.1, C405.2, C502.2, C504.2, C506.2, C508.2, L501.2, U401.5 (VL), U402.16 (VDD), U501.16 (VDD), U502.16 (VDD), U503.16 (VDD), U504.16 (VDD)
+15V: C201.1, L301.2, L303.1, U202.3 (VO)
+15V_F: C319.2, C321.2, C323.2, C325.2, C401.1, L301.1, U301.8 (V+), U302.8 (V+), U303.8 (V+), U304.8 (V+), U401.4 (V+)
-5V: C206.2, L502.2, L602.2, U203.3 (VO)
-5V_F: C404.1, C501.1, C503.1, C505.1, C507.1, L502.1, U402.7 (VEE), U501.7 (VEE), U502.7 (VEE), U503.7 (VEE), U504.7 (VEE)
-15V: C202.2, C211.2, D203.1 (K), L202.2, L302.1, L304.2, R203.2, U201.1 (SwC), U201.8 (DC), U203.2 (VI)
-15V_F: C320.1, C322.1, C324.1, C326.1, C402.1, L302.2, U301.4 (V-), U302.4 (V-), U303.4 (V-), U304.4 (V-), U401.7 (V-)
/IO Routing/U701_Q0: U401.6, U701.15 (QA)
/IO Routing/U701_Q1: U402.11 (A), U701.1 (QB)
/IO Routing/U701_Q2: U402.10 (B), U701.2 (QC)
/IO Routing/U701_Q3: U402.9 (C), U701.3 (QD)
/IO Routing/U701_Q4: U501.11 (A), U701.4 (QE)
/IO Routing/U701_Q5: U501.10 (B), U701.5 (QF)
/IO Routing/U701_Q6: U501.9 (C), U701.6 (QG)
/IO Routing/U701_Q7: U503.11 (A), U701.7 (QH)
/Inhibit Registers/U901_Q0: R901.2, U501.6 (INH), U901.15 (QA)
/Inhibit Registers/U901_Q1: R902.2, U503.6 (INH), U901.1 (QB)
/Inhibit Registers/U901_Q2: R903.2, U504.6 (INH), U901.2 (QC)
/Inhibit Registers/U901_Q3: R904.2, U502.6 (INH), U901.3 (QD)
/Inhibit Registers/U901_Q4: R905.2, U601.6 (INH), U901.4 (QE)
/Inhibit Registers/U901_Q5: R906.2, U603.6 (INH), U901.5 (QF)
/Inhibit Registers/U901_Q6: R907.2, U604.6 (INH), U901.6 (QG)
/Inhibit Registers/U901_Q7: R908.2, U602.6 (INH), U901.7 (QH)
/Matrix Shift Registers/U702_Q0: U503.10 (B), U702.15 (QA)
/Matrix Shift Registers/U702_Q1: U503.9 (C), U702.1 (QB)
/Matrix Shift Registers/U702_Q2: U504.11 (A), U702.2 (QC)
/Matrix Shift Registers/U702_Q3: U504.10 (B), U702.3 (QD)
/Matrix Shift Registers/U702_Q4: U504.9 (C), U702.4 (QE)
/Matrix Shift Registers/U702_Q5: U502.11 (A), U702.5 (QF)
/Matrix Shift Registers/U702_Q6: U502.10 (B), U702.6 (QG)
/Matrix Shift Registers/U702_Q7: U502.9 (C), U702.7 (QH)
/Matrix Shift Registers/U703_Q0: U601.11 (A), U703.15 (QA)
/Matrix Shift Registers/U703_Q1: U601.10 (B), U703.1 (QB)
/Matrix Shift Registers/U703_Q2: U601.9 (C), U703.2 (QC)
/Matrix Shift Registers/U703_Q3: U603.11 (A), U703.3 (QD)
/Matrix Shift Registers/U703_Q4: U603.10 (B), U703.4 (QE)
/Matrix Shift Registers/U703_Q5: U603.9 (C), U703.5 (QF)
/Matrix Shift Registers/U703_Q6: U604.11 (A), U703.6 (QG)
/Matrix Shift Registers/U703_Q7: U604.10 (B), U703.7 (QH)
/Matrix Shift Registers/U704_Q0: U604.9 (C), U704.15 (QA)
/Matrix Shift Registers/U704_Q1: U602.11 (A), U704.1 (QB)
/Matrix Shift Registers/U704_Q2: U602.10 (B), U704.2 (QC)
/Matrix Shift Registers/U704_Q3: U602.9 (C), U704.3 (QD)
/Power/24V_RAW_1: F201.2, J201.1
/Power/24V_RAW_2: D201.2 (A), F201.1
AGND: C201.2, C204.2, C205.2, C210.2, C211.1, C319.1, C320.2, C321.1, C322.2, C323.1, C324.2, C325.1, C326.2, C327.1, C328.2, C329.1, C330.2, C331.1, C332.2, C333.1, C334.2, C335.1, C336.2, C401.2, C402.2, C403.2, C404.2, C405.1, C501.2, C502.1, C503.2, C504.1, C505.2, C506.1, C507.2, C508.1, C601.2, C602.2, C603.1, C604.1, C605.2, C606.1, C607.2, C608.1, D203.2 (A), J301.S, J302.S, J303.S, J304.S, J305.S, J306.S, J307.S, J308.S, J309.S, J310.S, J311.S, J312.S, J313.S, J314.S, J315.S, J316.S, J317.S, J318.S, L202.1, NT101.2, R202.2, U201.2 (SwE), U201.4 (GND), U202.2 (GND), U401.3 (GND), U402.6 (INH), U402.8 (VSS), U501.8 (VSS), U502.8 (VSS), U503.8 (VSS), U504.8 (VSS), U601.8 (VSS), U602.8 (VSS), U603.8 (VSS), U604.8 (VSS)
FX_R_1: U301.1 (1OUT), U301.2 (1-), U402.13 (X0), U502.14 (X1), U503.14 (X1), U504.14 (X1), U601.14 (X1), U602.14 (X1), U603.14 (X1), U604.14 (X1)
FX_R_2: U301.6 (2-), U301.7 (2OUT), U402.14 (X1), U501.14 (X1), U502.15 (X2), U504.15 (X2), U601.15 (X2), U602.15 (X2), U603.15 (X2), U604.15 (X2)
FX_R_3: U302.1 (1OUT), U302.2 (1-), U402.15 (X2), U501.15 (X2), U502.12 (X3), U503.15 (X2), U601.12 (X3), U602.12 (X3), U603.12 (X3), U604.12 (X3)
FX_R_4: U302.6 (2-), U302.7 (2OUT), U402.12 (X3), U501.12 (X3), U503.12 (X3), U504.12 (X3), U601.1 (X4), U602.1 (X4), U603.1 (X4), U604.1 (X4)
FX_R_5: U303.1 (1OUT), U303.2 (1-), U402.1 (X4), U501.1 (X4), U502.1 (X4), U503.1 (X4), U504.1 (X4), U602.5 (X5), U603.5 (X5), U604.5 (X5)
FX_R_6: U303.6 (2-), U303.7 (2OUT), U402.5 (X5), U501.5 (X5), U502.5 (X5), U503.5 (X5), U504.5 (X5), U601.5 (X5), U602.2 (X6), U604.2 (X6)
FX_R_7: U304.1 (1OUT), U304.2 (1-), U402.2 (X6), U501.2 (X6), U502.2 (X6), U503.2 (X6), U504.2 (X6), U601.2 (X6), U602.4 (X7), U603.2 (X6)
FX_R_8: U304.6 (2-), U304.7 (2OUT), U402.4 (X7), U501.4 (X7), U502.4 (X7), U503.4 (X7), U504.4 (X7), U601.4 (X7), U603.4 (X7), U604.4 (X7)
FX_S_1: U305.3 (1+), U501.3 (X)
FX_S_2: U305.5 (2+), U503.3 (X)
FX_S_3: U306.3 (1+), U504.3 (X)
FX_S_4: U306.5 (2+), U502.3 (X)
FX_S_5: U307.3 (1+), U601.3 (X)
FX_S_6: U307.5 (2+), U603.3 (X)
FX_S_7: U308.3 (1+), U604.3 (X)
FX_S_8: U308.5 (2+), U602.3 (X)
GND: C101.1, C102.1, C103.1, C104.1, C105.1, C106.1, C107.1, C108.1, C109.1, C110.1, C202.1, C206.1, C208.2, C209.2, C701.2, C702.2, C703.2, C704.2, C901.2, D202.2 (A), Disp101.4 (GND), J201.2, J801.1, NT101.1, RV101.3, SW101.2, SW102.2, SW103.2, SW104.2, SW105.2, SW106.2, SW107.2, SW108.2, SW109.2, SW110.2, U101.22 (GND), U101.23 (GND), U101.24 (GND), U101.44 (GND), U203.1 (GND), U205.3 (GND), U205.5 (~ON/OFF), U701.8 (GND), U702.8 (GND), U703.8 (GND), U704.8 (GND), U901.8 (GND)
GUITAR_IN: C337.2, U401.8, U501.13 (X0), U502.13 (X0), U503.13 (X0), U504.13 (X0), U601.13 (X0), U602.13 (X0), U603.13 (X0), U604.13 (X0)
INHIBIT_SR_DS: U101.32 (GPIO35), U901.14 (SER)
MATRIX_OUT_PRE: U309.5 (2+), U401.1
MATRIX_SR_DS: U101.9 (GPIO16/ADC2_CH5/32K_N), U701.14 (SER)
unnamed: C301.1, J301.T
unnamed: C301.2, R301.2
unnamed: C302.1, J302.T
unnamed: C302.2, R302.2
unnamed: C303.1, J303.T
unnamed: C303.2, R303.2
unnamed: C304.1, J304.T
unnamed: C304.2, R304.2
unnamed: C305.1, J305.T
unnamed: C305.2, R305.2
unnamed: C306.1, J306.T
unnamed: C306.2, R306.2
unnamed: C307.1, J307.T
unnamed: C307.2, R307.2
unnamed: C308.1, J308.T
unnamed: C308.2, R308.2
unnamed: C309.1, J309.T
unnamed: C309.2, R309.2
unnamed: C310.1, J310.T
unnamed: C310.2, R310.2
unnamed: C311.1, J311.T
unnamed: C311.2, R311.2
unnamed: C312.1, J312.T
unnamed: C312.2, R312.2
unnamed: C313.1, J313.T
unnamed: C313.2, R313.2
unnamed: C314.1, J314.T
unnamed: C314.2, R314.2
unnamed: C315.1, J315.T
unnamed: C315.2, R315.2
unnamed: C316.1, J316.T
unnamed: C316.2, R316.2
unnamed: C317.1, J317.T
unnamed: C317.2, R317.2
unnamed: C318.1, J318.T
unnamed: D101.1 (K), R101.1
unnamed: D202.1 (K), L201.2, U205.4 (FB)
unnamed: Disp101.1 (VCC), JP101.2 (C)
unnamed: R101.2, RV101.2
unnamed: C101.2, SW101.1, U101.6 (GPIO6/ADC1_CH5)
unnamed: C103.2, SW103.1, U101.7 (GPIO7/ADC1_CH6)
unnamed: C105.2, SW105.1, U101.12 (GPIO8/ADC1_CH7)
unnamed: C107.2, SW107.1, U101.15 (GPIO9/ADC1_CH8)
unnamed: C109.2, SW109.1, U101.16 (GPIO10/ADC1_CH9)
unnamed: C102.2, SW102.1, U101.17 (GPIO11/ADC2_CH0)
unnamed: C104.2, SW104.1, U101.18 (GPIO12/ADC2_CH1)
unnamed: C106.2, SW106.1, U101.19 (GPIO13/ADC2_CH2)
unnamed: C108.2, SW108.1, U101.20 (GPIO14/ADC2_CH3)
unnamed: C110.2, SW110.1, U101.8 (GPIO15/ADC2_CH4/32K_P)
unnamed: R201.2, U201.7 (Ipk)
unnamed: C210.1, U201.3 (TC)
unnamed: R202.1, R203.1, U201.5 (Vfb)
unnamed: R301.1, U301.3 (1+)
unnamed: R302.1, U301.5 (2+)
unnamed: R303.1, U302.3 (1+)
unnamed: R304.1, U302.5 (2+)
unnamed: R305.1, U303.3 (1+)
unnamed: R306.1, U303.5 (2+)
unnamed: R307.1, U304.3 (1+)
unnamed: R308.1, U304.5 (2+)
unnamed: R309.1, U305.1 (1OUT), U305.2 (1-)
unnamed: R310.1, U305.6 (2-), U305.7 (2OUT)
unnamed: C327.2, C329.2, C331.2, C333.2, C335.2, L303.2, U305.8 (V+), U306.8 (V+), U307.8 (V+), U308.8 (V+), U309.8 (V+)
unnamed: C328.1, C330.1, C332.1, C334.1, C336.1, L304.1, U305.4 (V-), U306.4 (V-), U307.4 (V-), U308.4 (V-), U309.4 (V-)
unnamed: R311.1, U306.1 (1OUT), U306.2 (1-)
unnamed: R312.1, U306.6 (2-), U306.7 (2OUT)
unnamed: R313.1, U307.1 (1OUT), U307.2 (1-)
unnamed: R314.1, U307.6 (2-), U307.7 (2OUT)
unnamed: R315.1, U308.1 (1OUT), U308.2 (1-)
unnamed: R316.1, U308.6 (2-), U308.7 (2OUT)
unnamed: R317.1, U309.3 (1+)
unnamed: C337.1, U309.1 (1OUT), U309.2 (1-)
unnamed: C318.2, U309.6 (2-), U309.7 (2OUT)
unnamed: U401.2, U402.3 (X)
unnamed: C603.2, C604.2, C606.2, C608.2, L601.2, U601.16 (VDD), U602.16 (VDD), U603.16 (VDD), U604.16 (VDD)
unnamed: C601.1, C602.1, C605.1, C607.1, L602.1, U601.7 (VEE), U602.7 (VEE), U603.7 (VEE), U604.7 (VEE)
unnamed: U701.9 (QH'), U702.14 (SER)
unnamed: U702.9 (QH'), U703.14 (SER)
unnamed: U703.9 (QH'), U704.14 (SER)
SCL: Disp101.3 (SCL), J801.3, U101.5 (GPIO5/ADC1_CH4)
SDA: Disp101.2 (SDA), J801.4, U101.4 (GPIO4/ADC1_CH3)
SR_OE: U101.25 (GPIO19/USB_D-), U701.13 (~OE), U702.13 (~OE), U703.13 (~OE), U704.13 (~OE), U901.13 (~OE)
SR_SHCP: U101.10 (GPIO17/ADC2_CH6), U701.11 (SRCLK), U702.11 (SRCLK), U703.11 (SRCLK), U704.11 (SRCLK), U901.11 (SRCLK)
SR_STCP: U101.11 (GPIO18/ADC2_CH7), U701.12 (RCLK), U702.12 (RCLK), U703.12 (RCLK), U704.12 (RCLK), U901.12 (RCLK)
VIN_24V: C204.1, C205.1, C209.1, D201.1 (K), R201.1, U201.6 (Vin), U202.1 (VI), U205.1 (VIN)

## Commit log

2025-06-16 Initial commit for new subrepo
    [Buffers.kicad_sch, Inhibit.kicad_sch, LEDS.kicad_sch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]
2025-06-17 New cooler (thermally) power supply.
    [Power.kicad_sch, circuit.kicad_pcb, circuit.kicad_sch]
2025-06-21 Removed un-needed inhibit from amp out. thereby simplifying the shift registers.
    [Inhibit.kicad_sch, circuit.kicad_pcb, circuit.kicad_sch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]
2025-06-21 Removed LED Shift registers and replaced them with PCA9685 PWM controllers, Also changed LEDs to RGB LEDs.
    [Adafruit PCA9685 rev C.kicad_sch, Adafruit PCA9685 rev C_2.kicad_sch, Buffers.kicad_sch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]
2025-06-22 Added Datasheets and specified polyfuse parameters.
    [Power.kicad_sch, circuit.kicad_sch, io_routing.kicad_sch]
